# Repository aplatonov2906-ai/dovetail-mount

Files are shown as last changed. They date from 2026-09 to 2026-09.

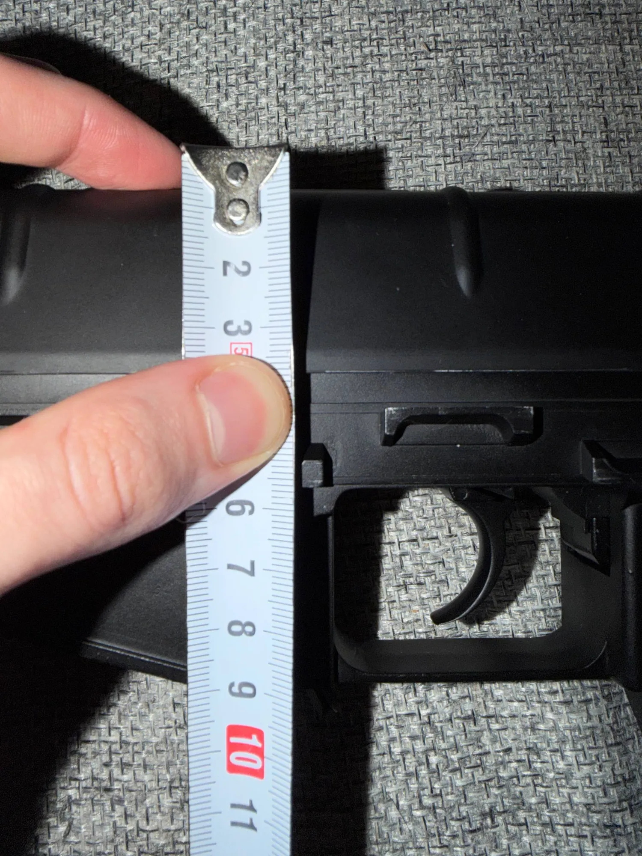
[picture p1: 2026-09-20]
ref/rail_side_measured.webp

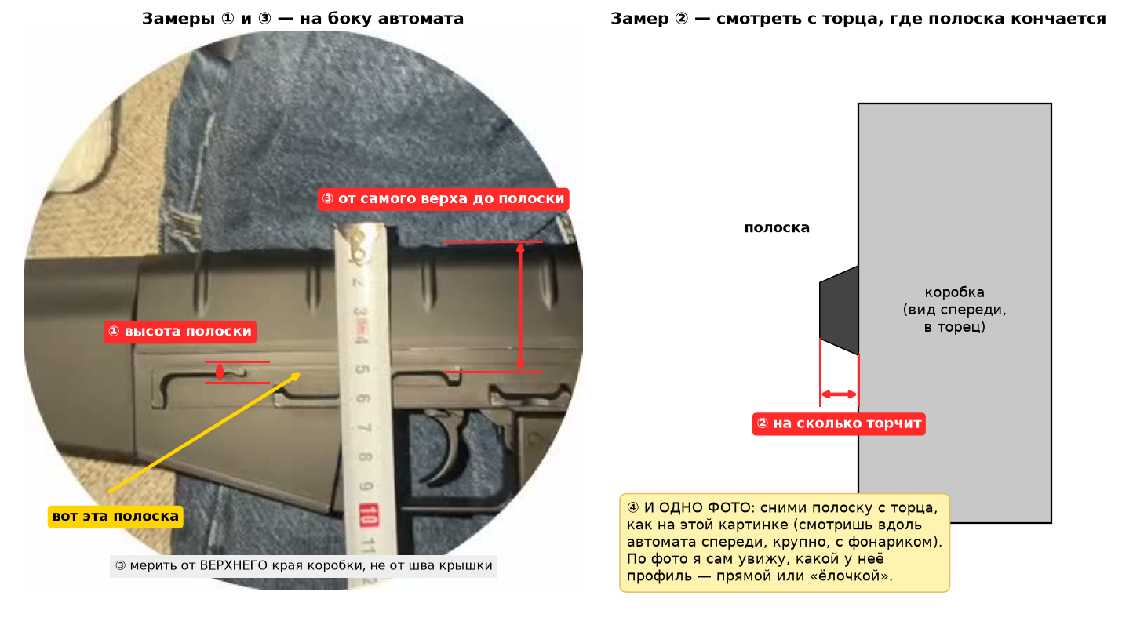
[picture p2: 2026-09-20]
ref/measure_simple.png

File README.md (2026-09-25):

# dovetail-mount — кронштейн «ласточкин хвост» → Пикатинни (3D-печать)

**3D-просмотр в браузере:** https://aplatonov2906-ai.github.io/dovetail-mount/viewer.html?v=3
(переключатель версий вверху; крутить мышью, колесо — зум, галочки — скрыть детали, «разнести губку»)

**Схема, что замерить штангенциркулем:** [ref/measure.png](ref/measure.png)

Кронштейн на боковую планку для страйкбольной реплики, по образцу кронштейна
ТОЧМАШ для СР-3МП. Форма снята с игровой модели прототипа
(`ref/proto_sr3mp_mount.obj`, силуэт и сечения в `ref/proto_*.png`): от паза
стенка идёт вверх и дугой загибается внутрь над коробкой, на вершине дуги
верхняя планка Пикатинни с 11 сквозными отверстиями в основании, боковая планка
на 8 пазов спереди, задний нижний угол срезан наискось с упором и отверстием,
нижняя губка отдельной деталью на двух винтах сверху.

Отличия от прототипа под реплику: паз под планку 15 мм с выступом 5,5 (в игровой
модели паза нет), нижняя стенка 11 мм вместо 5 (пластик, за пазом должно
остаться тело), дуга поднята, потому что планка на коробке сидит низко — верх
Пикатинни получается на 18 мм выше верха коробки (ниже нельзя: дуга упрётся в
край крышки), ось планки на 8 мм левее оси ствола. Кронштейн под левую сторону
коробки, где планка.

Модель параметрическая: [mount.py](mount.py) (CadQuery). Результат в `out/`:

| Файл | Что это |
|---|---|
| `mount_body.stl` | тело кронштейна (верхняя планка 14 пазов, боковая планка 8 пазов) |
| `mount_jaw.stl` | нижняя губка, отдельная деталь |
| `test_body.stl`, `test_jaw.stl` | **тест посадки** — короткий кусок зоны зажима, печатать первым |
| `mount.step` | сборка для любого CAD |
| `exact_body.stl`, `exact_jaw.stl`, `exact_test_*.stl`, `exact_assembly.stl` | **точная копия** игровой модели (`mount_exact.py`). Родной зажим исходника (зуб сверху, губа на губке снизу, `ref/proto_native_clamp.png`): планка друга ложится после снятия ~0,7 мм с корня зуба и губы. Разъём по низу тела: губка — нижние 14 мм родного бруска, его верх со стержнями остаётся у тела полкой. Два винта М3×16 с цилиндрической головкой **сверху** по оси стержней (стержни исходника — это головки винтов, на их месте площадки Ø6), проход сквозь полку Ø3,4, резьба в губке (глухое Ø2,5). Добавлено: ничего (`out/diff_exact.png`). На этой реплике дуга оригинала заходит в крышку коробки (`preview_exact.png`, синий пунктир) |
| `preview.png`, `preview_exact.png` | виды + сечение (удлинённая / точная копия) |

## Что известно о планке (замеры друга 21.09.2026)

- Верх планки — 42–43 мм от верха коробки; сама планка 15 мм по высоте.
  В модели: центр планки на 50 мм от верха (`RECV_TOP`), `DT_FACE` = 15.
- Планка отлита заодно с коробкой, **шире у лица и уже у корня** (подрез к коробке,
  видно на торцевом фото `ref/rail_end.jpg`). Угол подреза не мерили; в точной копии
  взяты родные углы зуба и губы исходника (~22°/16°). Выступ над коробкой 5–6 мм (замер друга), `DT_DEPTH` = 5,5. Угол скосов не мерили, заложено 45°.
- Короткий паз с «крючком» на боку коробки — это не планка, а фиксатор
  штатного кронштейна (длина ≈ 17 мм), в модели не участвует.
- Не подтверждено: угол скосов. Зазор `DT_CLEAR` 0,25.

## Сначала тест посадки

Прежде чем печатать тело целиком (≈92 см³), напечатать `test_body` + `test_jaw`,
посадить на планку и стянуть двумя винтами М4×30 сверху. Не лезет — увеличить `DT_CLEAR`;
болтается — уменьшить. Если губка упирается в тело раньше, чем зажмёт планку —
увеличить `DT_DEPTH`. Все параметры в шапке `mount.py`, пересборка `build.cmd`.

## Крепёж

- удлинённая версия: 2 × М4×30 DIN 912 сверху + 2 гайки М4 в губке;
- точная копия: 2 × М3×16 с цилиндрической головкой DIN 912 сверху, без гаек (резьба
  в пластике губки, глухое отверстие Ø2,5). Губка при затяжке не доходит до тела 0,8 мм — это натяг,
  так и задумано.

## Печать

- Ориентация тела: как стоит на оружии (верхняя планка сверху), низом на
  стол; задний срез и козырьки планок — с поддержками. Губка — плоской
  стороной вниз, без поддержек.
- Пластик: PETG/ABS/ASA/нейлон. PLA только для примерки.
- 100 % заполнение или ≥ 6 периметров, слой 0,2.
- Верхняя планка после печати — прогнать надфилем пазы, если прицел садится туго.

## Пересборка

`build.cmd` или `python mount.py && python render.py`
(нужны `pip install cadquery trimesh matplotlib`).

## Референс

`ref/` — фото прототипа и расшифровка голосовых (`transcript.txt`).
Ключевые размеры из видео с рулеткой: центр полоски ≈ 46 мм от верха коробки,
высота коробки ≈ 53 мм, длина полоски ≈ 90 мм. Голосом друг называл «3,3» —
похоже, это шов крышки, не полоска; уточнить.

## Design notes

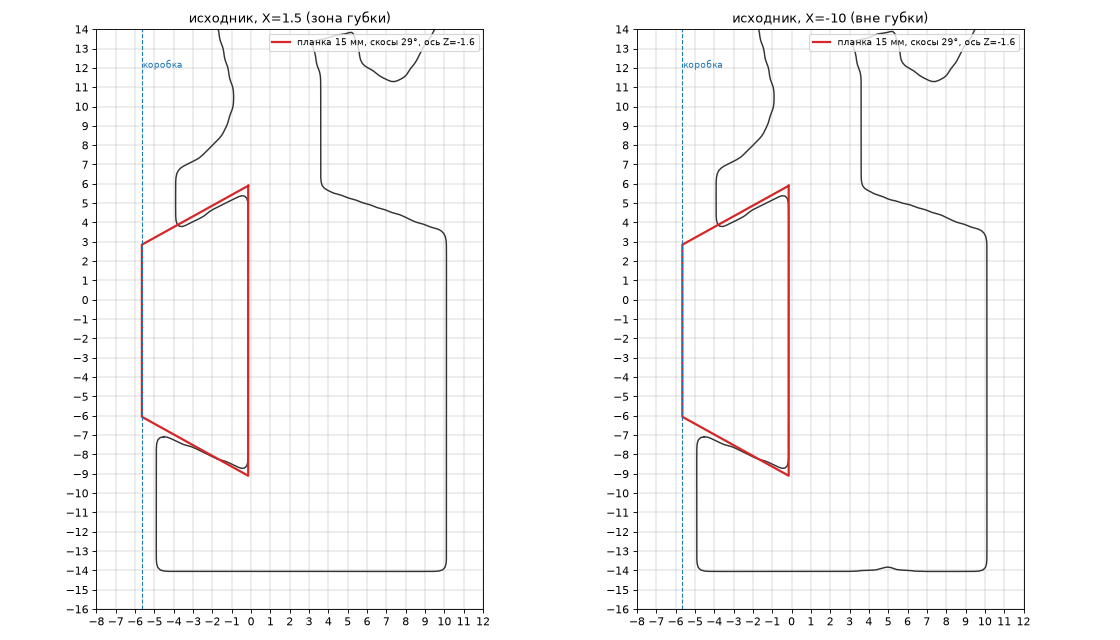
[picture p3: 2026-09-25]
ref/proto_native_clamp.png

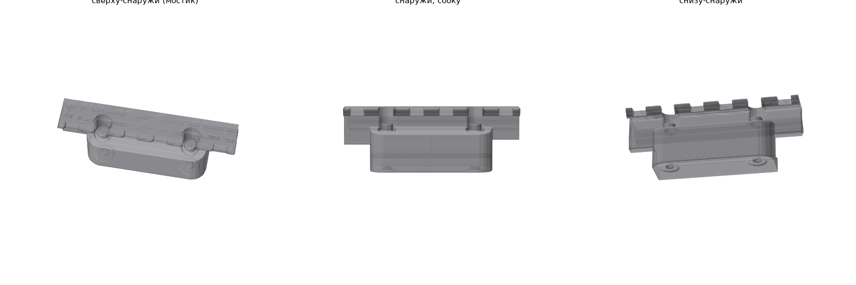
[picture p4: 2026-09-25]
ref/proto_boss_zone.png

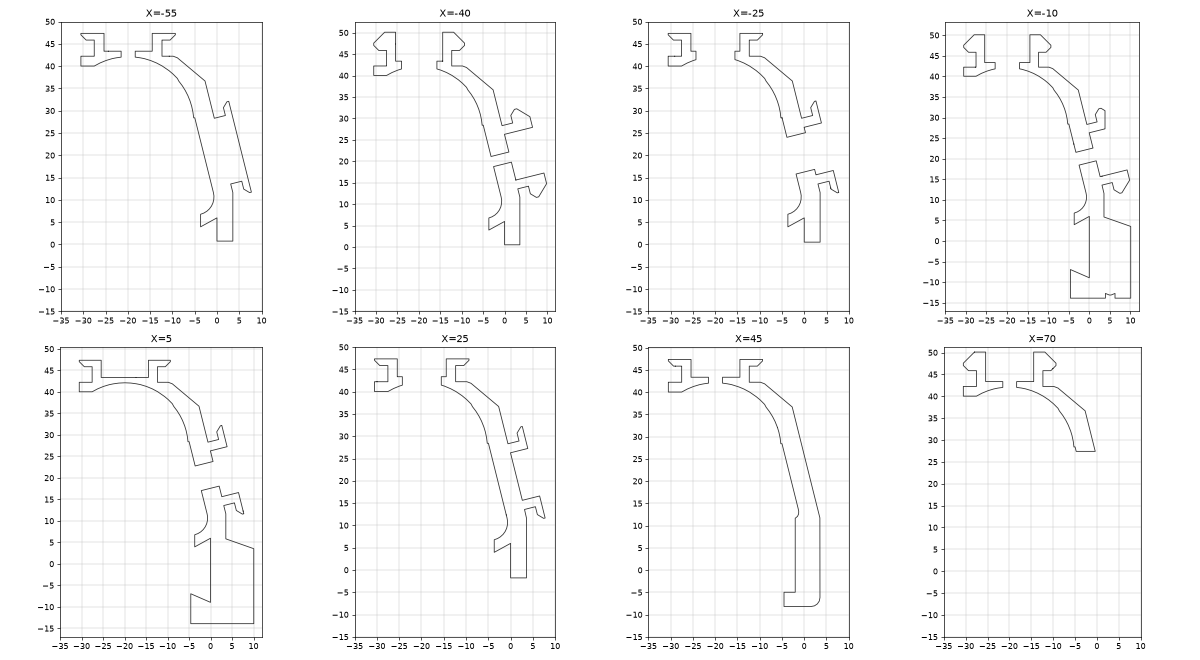
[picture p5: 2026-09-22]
ref/proto_sections.png

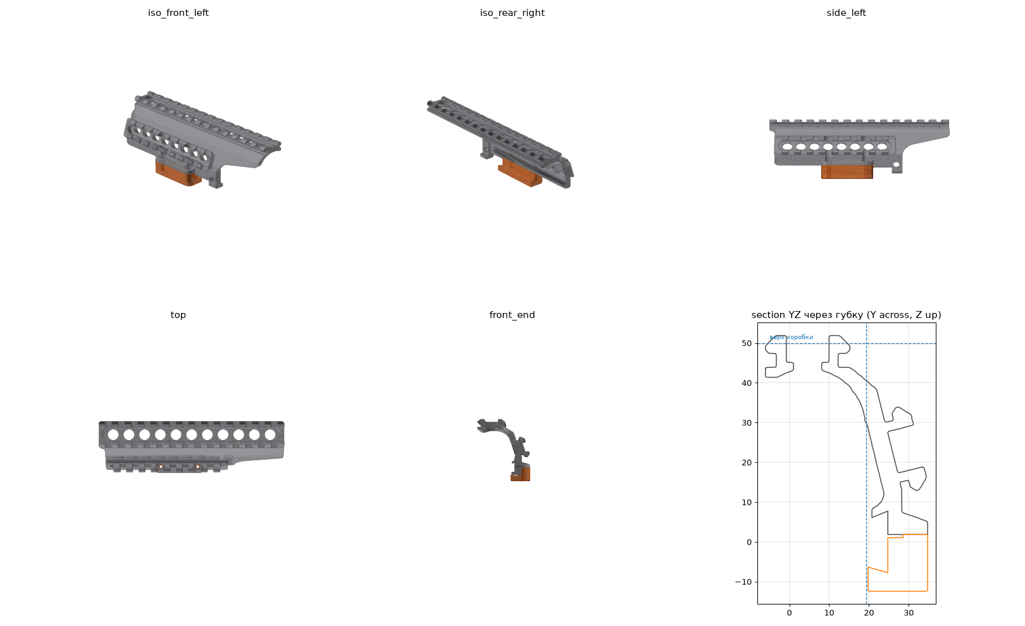
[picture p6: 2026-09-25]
out/preview_exact.png

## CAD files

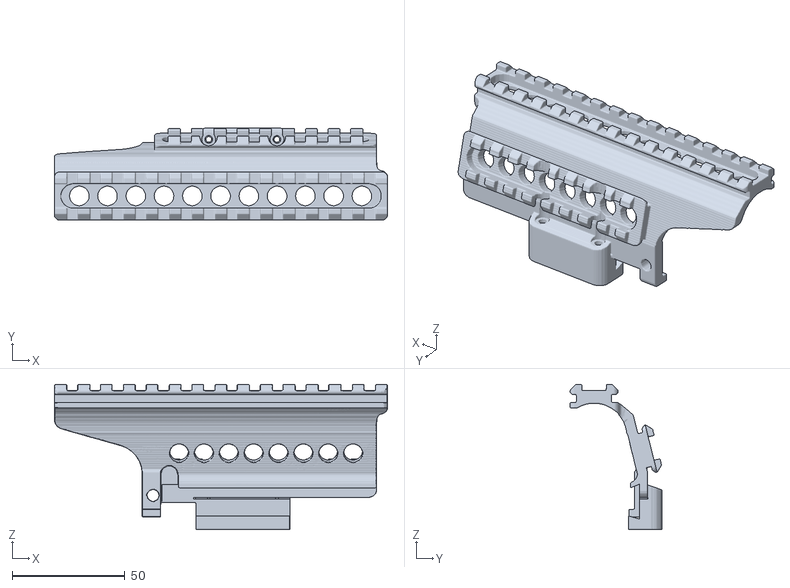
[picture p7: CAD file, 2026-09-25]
out/exact_assembly.stl
147.4 x 40.9 x 64.3

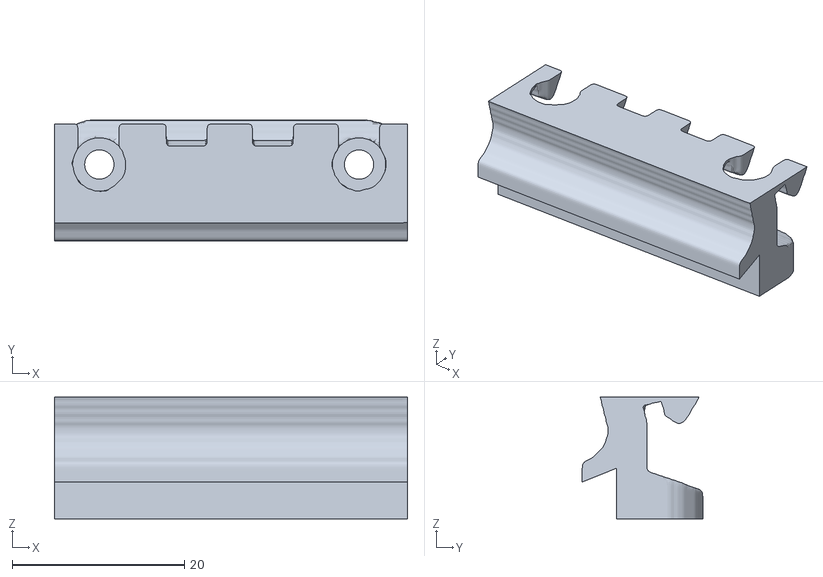
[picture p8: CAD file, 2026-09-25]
out/exact_test_body.stl
41.0 x 14.0 x 14.1

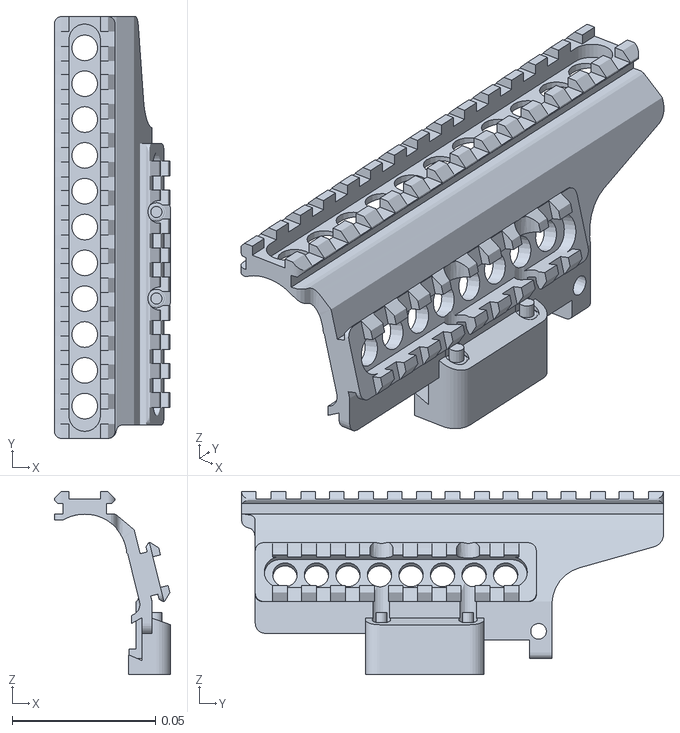
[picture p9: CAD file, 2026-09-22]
ref/proto_sr3mp_mount.obj
0.0406 x 0.147 x 0.064

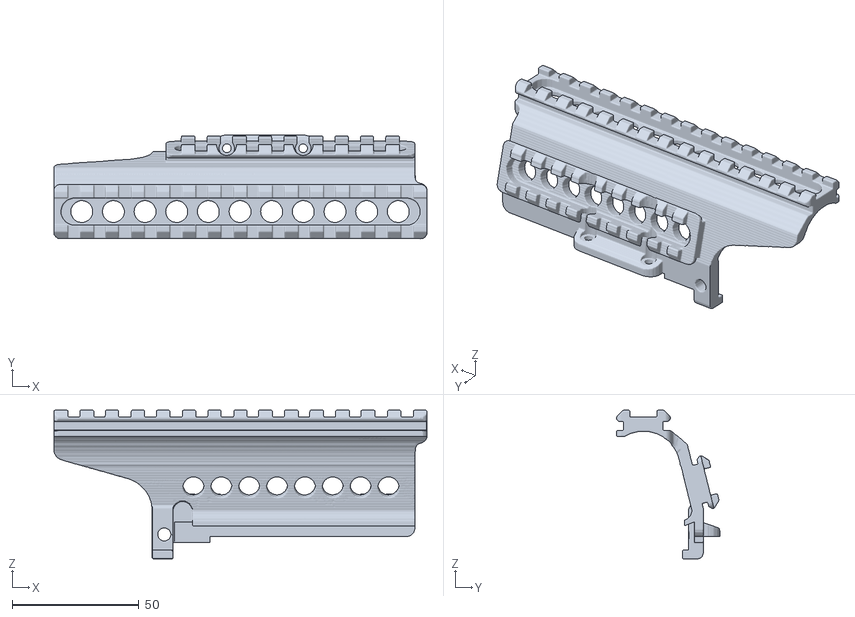
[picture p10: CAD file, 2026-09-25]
out/exact_body.stl
147.4 x 40.9 x 58.8

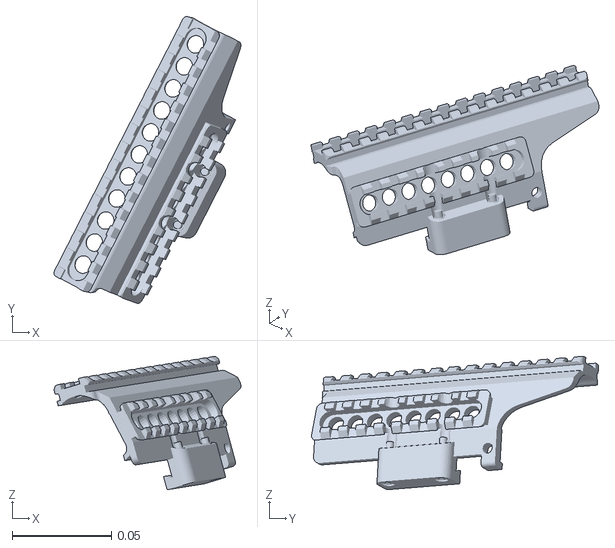
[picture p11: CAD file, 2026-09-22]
ref/proto_ono_samoe_2.stl
0.0942 x 0.145 x 0.0673

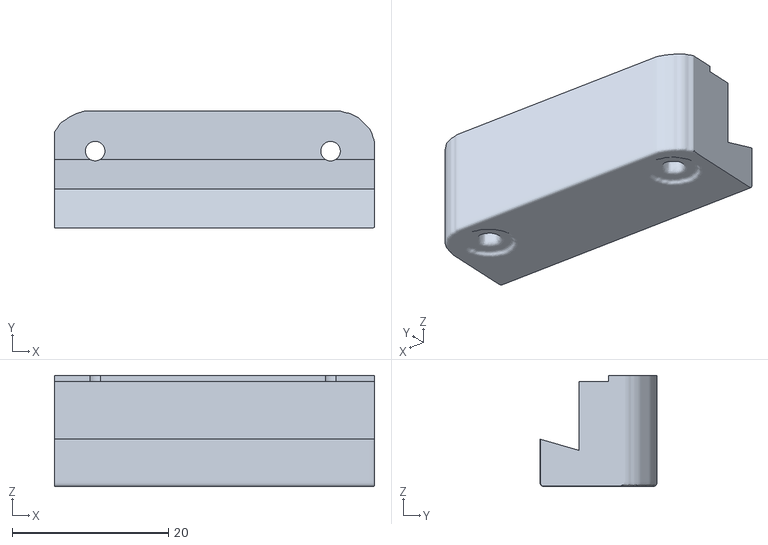
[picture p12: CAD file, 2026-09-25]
out/exact_test_jaw.stl
41.0 x 15.0 x 14.3

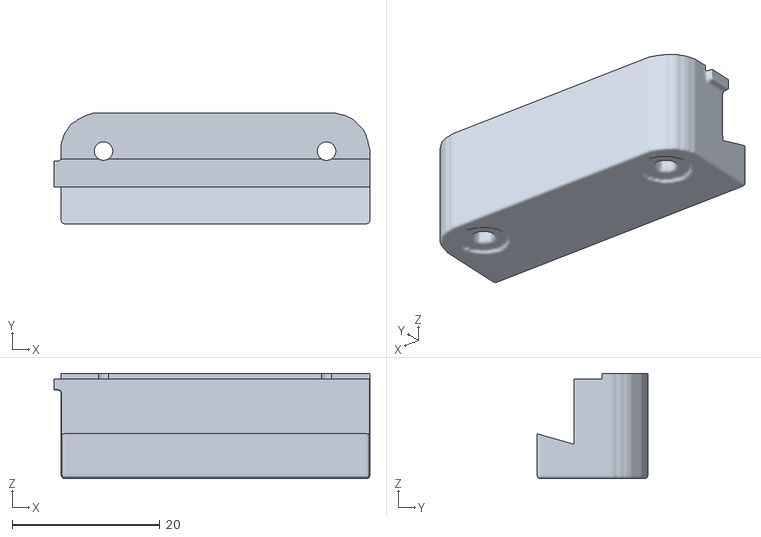
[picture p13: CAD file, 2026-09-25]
out/exact_jaw.stl
42.8 x 15.0 x 14.3

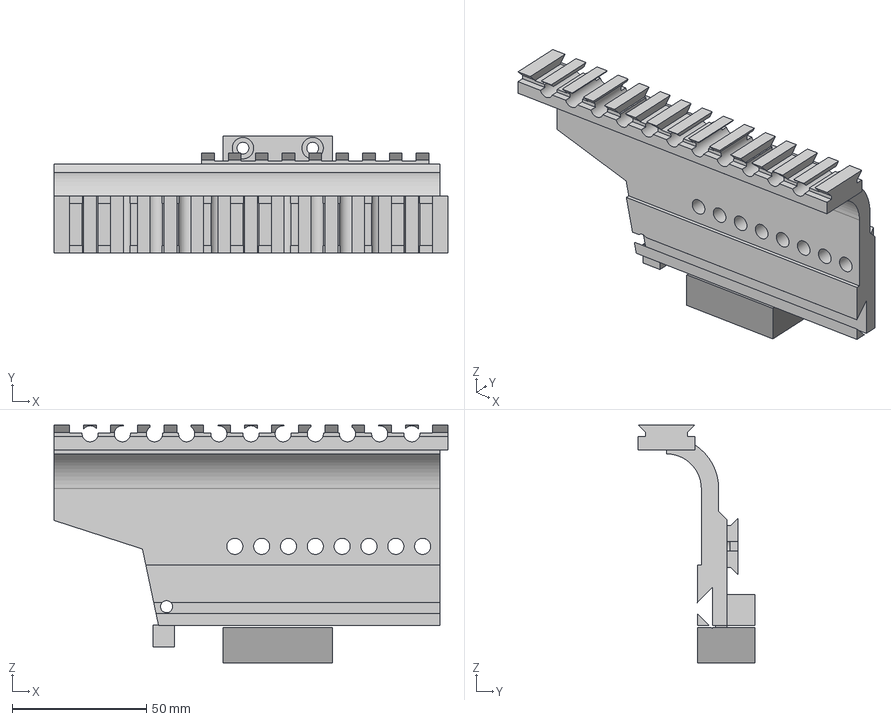
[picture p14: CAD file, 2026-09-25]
out/mount.step
147.0 x 43.6 x 88.8 mm
jaw

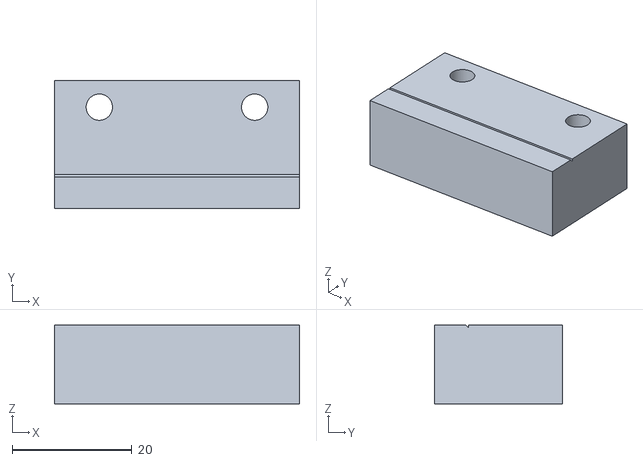
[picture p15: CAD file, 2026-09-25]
out/test_jaw.stl
41.0 x 21.5 x 13.2

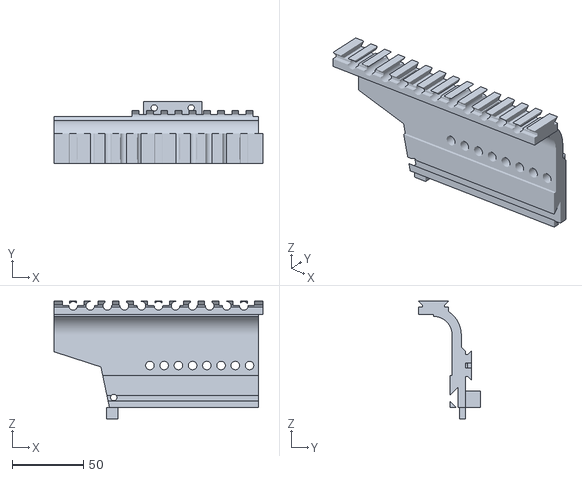
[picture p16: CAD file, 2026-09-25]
out/mount_body.stl
147.0 x 43.6 x 82.8

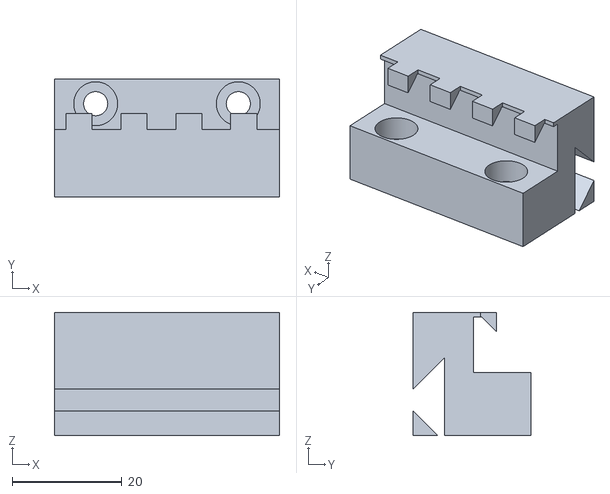
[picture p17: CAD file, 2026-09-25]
out/test_body.stl
41.0 x 21.5 x 22.5

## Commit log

2026-09-20 Кронштейн ласточкин хвост → Пикатинни: параметрическая модель CadQuery, STL/STEP, тест посадки
    [mount.step, mount_body.stl, mount_jaw.stl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]
2026-09-20 Параметры под тонкую полоску реплики (4,5 мм, 46 мм от верха), схема замеров
    [mount.step, mount_body.stl, mount_jaw.stl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]
2026-09-20 3D-просмотр в браузере (viewer.html, three.js)
2026-09-20 README: ссылки на 3D-просмотр и схему замеров
2026-09-20 Простая схема замеров на кадре автомата
2026-09-20 Планка 15 мм, верх на 42,5 мм от верха коробки (замеры), фото торца планки
    [mount.step, mount_body.stl, mount_jaw.stl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]
2026-09-20 Выступ планки 5,5 мм по замеру
    [mount.step, mount_body.stl, mount_jaw.stl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]
2026-09-20 Вид как у прототипа: наклонная грань с отверстиями, косой срез спереди, задний упор; просмотрщик без кэша
    [mount.step, mount_body.stl, test_body.stl]
2026-09-20 Нижняя полка во всю длину как у прототипа; фото торца старого кронштейна
    [mount.step, mount_body.stl, test_body.stl]
2026-09-20 Схема как у прототипа: пластина на боку коробки, планка на брусе с отверстиями, задний срез, винты губки сверху
    [mount.step, mount_body.stl, mount_jaw.stl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]
2026-09-22 Форма по игровой модели прототипа ТОЧМАШ СР-3МП: дуга над коробкой, отверстия в основании планки, задний срез по силуэту
    [mount.step, mount_body.stl, mount_jaw.stl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]
2026-09-25 Ширина коробки по штангенциркулю: низ 38,5, крышка 36,5, выступ планки 5,5 подтверждён
    [mount.step, mount_body.stl, mount_jaw.stl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]
2026-09-25 Зеркало под левую сторону коробки, дуга ниже (планка на 18 мм над крышкой)
    [mount.step, mount_body.stl, mount_jaw.stl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]
2026-09-25 Точная копия игровой модели: заливка оболочки в тело, паз, губка, болты; переключатель версий в просмотрщике
    [exact_body.stl, exact_jaw.stl, exact_test_body.stl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]
2026-09-25 Промежуточное залитое тело не хранить в репозитории (генерируется ref/solidify.py)
2026-09-25 Просмотрщик: точная копия по умолчанию, без кэша страницы
2026-09-25 Точная копия: винты М4×20 сверху через мостик, как у оригинала; гайки в губке
    [exact_body.stl, exact_jaw.stl, exact_test_body.stl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]
2026-09-25 Точная копия: утолщение за пазом минимальное (2,5 мм), мостик 12,5
    [exact_body.stl, exact_jaw.stl, exact_test_body.stl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]
2026-09-25 Точная копия без добавленной геометрии: паз на 3 мм захвата, родная губка и мостик, винты сверху
    [exact_body.stl, exact_jaw.stl, exact_test_body.stl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]
2026-09-25 Точная копия: верхняя губка — родной зуб оригинала, паз под ним, родная нижняя губка удлинена под планку 15 мм
    [exact_body.stl, exact_jaw.stl, exact_test_body.stl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]
2026-09-25 Точная копия: минимальные отличия — зуб подрезан под скос (скрыто), губка +2,7 мм; скрипт разницы с исходником
    [exact_body.stl, exact_jaw.stl, exact_test_body.stl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]
2026-09-25 Точная копия на родном зажиме исходника: ёлочка правильной стороны (планка шире у лица), губка родной высоты, добавлено ничего
    [exact_body.stl, exact_jaw.stl, exact_test_body.stl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]
2026-09-25 Точная копия: гайки в скрытых карманах сверху губки, файл сборки для просмотра
    [exact_assembly.stl, exact_jaw.stl, exact_test_jaw.stl]
2026-09-25 Точная копия: винты М3 снизу по родным стержням, потаи в родных гнёздах на дне губки, втулки под гайки; удалена мёртвая функция
    [exact_assembly.stl, exact_body.stl, exact_jaw.stl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]
2026-09-25 Канал до заднего упора, осколки булевых операций отбрасываются
    [exact_assembly.stl, exact_body.stl]
2026-09-25 Экспорт: только основная связная часть, ремонт сетки
    [exact_test_body.stl]
2026-09-25 Точная копия: без втулок, родные стержни на губке, винты М3×35 снизу в резьбу в стенке
    [exact_assembly.stl, exact_body.stl, exact_jaw.stl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]
2026-09-25 Точная копия: полка со стержнями у тела, губка — низ бруска, винты М3×20 снизу по оси стержней в глухую резьбу
    [exact_assembly.stl, exact_body.stl, exact_jaw.stl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]
2026-09-25 Точная копия: винты М3×16 сверху по оси стержней, площадки под головки на полке, резьба в губке
    [exact_assembly.stl, exact_body.stl, exact_jaw.stl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]
